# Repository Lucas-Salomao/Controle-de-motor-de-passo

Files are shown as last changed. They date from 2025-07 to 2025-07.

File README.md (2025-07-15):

# Controlador de Motor de Passo com Menu via Encoder e Display OLED

> Um sistema de controle preciso para motores de passo, com interface de usuário baseada em menu, desenvolvido para a plataforma ESP32 com PlatformIO.
> 

Este projeto oferece um controle detalhado para um motor de passo, utilizando um encoder rotativo para navegar por um menu de funções em um display OLED. O sistema é ideal para aplicações que exigem movimentos precisos e repetitivos, como em gabaritos, sistemas de automação de pequeno porte ou equipamentos de teste.

O usuário pode executar um ciclo completo de operação, posicionar o motor em um passo específico, ajustar a resolução do passo (micro-passo), configurar o tempo de acionamento de um relé e desabilitar o motor para movimento livre.

*Última atualização: 15 de Julho de 2025*

## ✨ Funcionalidades Principais

- **Interface de Menu Intuitiva:** Todas as funções são acessadas através de um menu no display OLED, controlado pelo encoder rotativo.
- **Ciclo de Operação Completo:** Executa uma volta completa, acionando um relé em cada passo por um tempo configurável.
- **Posicionamento Preciso:** Permite ao usuário escolher um passo exato (posição) para o qual o motor deve se mover.
- **Movimento Otimizado:** O motor sempre gira pelo caminho mais curto para alcançar a posição de destino.
- **Configuração de Micro-passo:** Suporte para ajustar a resolução do motor (Full, Half, 1/4, 1/8, e 1/16), permitindo um movimento mais suave e preciso.
- **Ajuste do Tempo do Relé:** O tempo em que o relé permanece ativo durante o ciclo completo pode ser ajustado e salvo pelo usuário.
- **Torque de Parada (Holding Torque):** As bobinas do motor permanecem energizadas na posição de destino para resistir a movimentos externos.
- **Modo de Giro Livre:** O motor pode ser facilmente desabilitado pelo menu para permitir o giro livre do eixo.
- **Altamente Configurável:** Pinos, passos do motor e outros parâmetros podem ser facilmente alterados no arquivo `config.h`.

## 🛠️ Componentes Necessários

| Componente | Quantidade | Observações |
| --- | --- | --- |
| ESP32 Dev Kit | 1 | Placa principal do projeto. |
| Driver de Motor de Passo A4988 | 1 | Ou similar (a lógica de micro-passo é para o A4988). |
| Motor de Passo NEMA 17 | 1 | Modelo de 200 passos/volta (1.8°). |
| Encoder Rotativo com Botão | 1 | Para entrada do usuário. |
| Display OLED I2C 0.96" | 1 | Modelo SSD1306 (128x64). |
| Módulo Relé 5V | 1 | Para acionar cargas externas. |
| Fonte de Alimentação Externa | 1 | Tensão e corrente compatíveis com o motor (ex: 12V 2A). |
| Cabos Jumper | Vários | Para realizar as conexões. |

## 📦 Software e Bibliotecas

Este projeto foi desenvolvido utilizando **PlatformIO** com o Visual Studio Code. As bibliotecas necessárias são gerenciadas automaticamente pelo `platformio.ini`.

- `adafruit/Adafruit GFX Library`: Biblioteca gráfica base para o display.
- `adafruit/Adafruit SSD1306`: Driver para o display OLED de 0.96".
- `Wire`: Para comunicação I2C com o display.

O projeto utiliza classes personalizadas (`StepperController`, `DisplayManager`, `EncoderHandler`) para modularizar o código, não dependendo de bibliotecas de motor externas como a AccelStepper.

## 🔌 Diagrama de Conexão (Wiring)

**Atenção:** A alimentação do motor (`VMOT` no A4988) **DEVE** vir de uma fonte externa. Não utilize o pino 5V/VIN do ESP32 para alimentar o motor. Conecte o GND da fonte externa ao GND do ESP32.

| Componente | Pino do Componente | Pino do ESP32 |
| --- | --- | --- |
| **Driver A4988** | `ENABLE` | `GPIO 27` |
|  | `STEP` | `GPIO 26` |
|  | `DIR` | `GPIO 25` |
|  | `MS1` | `GPIO 14` |
|  | `MS2` | `GPIO 12` |
|  | `MS3` | `GPIO 13` |
|  | `GND` | `GND` |
|  | `VDD` (Lógica) | `3.3V` ou `5V` |
|  | `VMOT` (Motor) | `+` da Fonte Externa |
|  | `GND` (Motor) | `-` da Fonte Externa |
| **Encoder** | `CLK` | `GPIO 18` |
|  | `DT` | `GPIO 19` |
|  | `SW` (Botão) | `GPIO 5` |
|  | `+` | `3.3V` |
|  | `GND` | `GND` |
| **Display OLED** | `SCL` | `GPIO 22` (Padrão I2C) |
|  | `SDA` | `GPIO` 21 (Padrão I2C) |
|  | `VCC` | `3.3V` |
|  | `GND` | `GND` |
| **Módulo Relé** | `IN` (Sinal) | `GPIO 32` |
|  | `VCC` | `5V` |
|  | `GND` | `GND` |

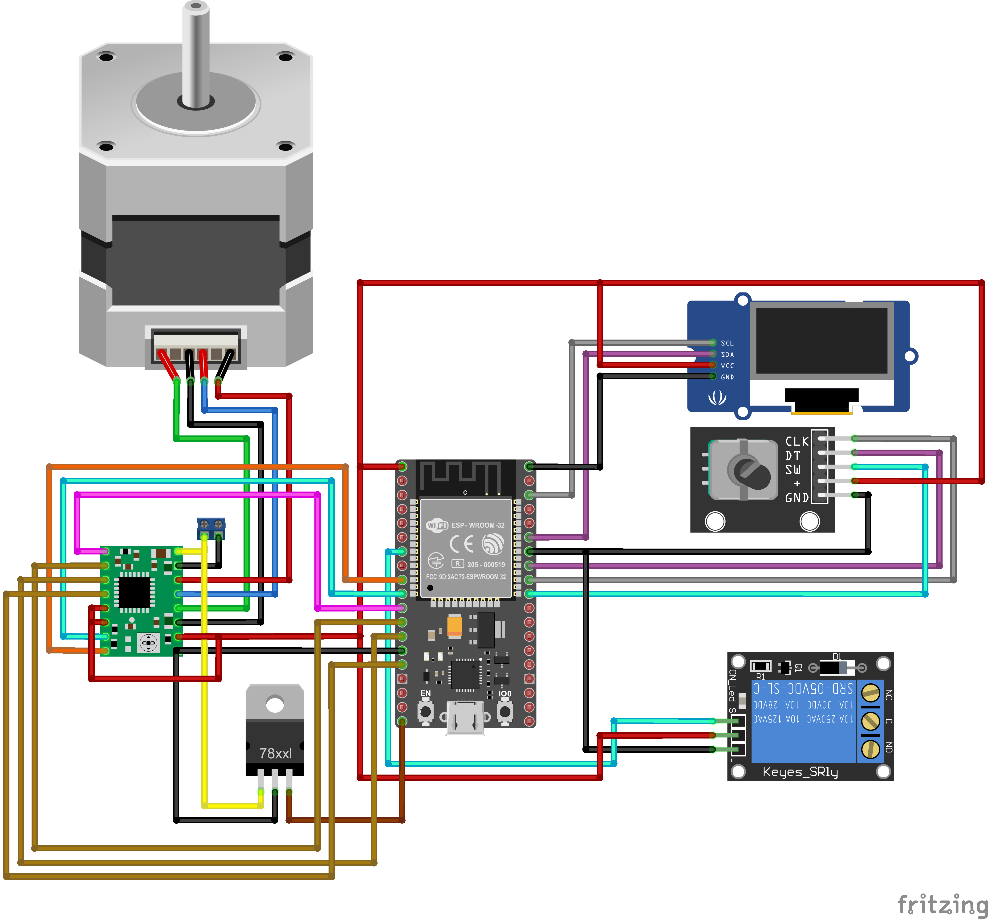
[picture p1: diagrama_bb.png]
Diagrama


## 📁 Estrutura do Projeto

O projeto está organizado em classes para facilitar a manutenção e a leitura do código.

```
.
├── platformio.ini         // Arquivo de configuração do PlatformIO
├── include
│   ├── config.h           // Configurações de pinos e parâmetros globais
│   ├── logo.h             // Bitmap da imagem de boot
│   ├── DisplayManager.h   // Cabeçalho da classe de controle do Display
│   ├── EncoderHandler.h   // Cabeçalho da classe de controle do Encoder
│   └── StepperController.h// Cabeçalho da classe de controle do Motor
└── src
    ├── main.cpp           // Lógica principal, máquina de estados e menus
    ├── DisplayManager.cpp   // Implementação da classe do Display
    ├── EncoderHandler.cpp   // Implementação da classe do Encoder
    └── StepperController.cpp// Implementação da classe do Motor

```

## ⚙️ Configuração

Antes de carregar o código, você pode verificar as configurações no arquivo `include/config.h` para que correspondam ao seu hardware.

### Mapeamento de Pinos

Se você precisar usar outros pinos no ESP32, pode alterá-los facilmente no `config.h`.

```
// --- Pinos de Controle de Micro-passo (A4988) ---
#define MS1_PIN         14
#define MS2_PIN         12
#define MS3_PIN         13

// Configurações do Motor de Passo
#define STEP_PIN        26
#define DIR_PIN         25
#define ENABLE_PIN      27

// Configurações do Encoder
#define ENCODER_CLK     18
#define ENCODER_DT      19
#define ENCODER_SW      5

// Configurações do Relé
#define RELAY_PIN       32

```

## 🚀 Como Usar

A operação do dispositivo é totalmente guiada pelo menu no display.

1. **Ligar o Dispositivo**
    - Ao receber energia, o display mostrará um logo por 2.5 segundos.
    - Em seguida, o Menu Principal será exibido.
2. **Navegando no Menu**
    - 🔄 **Girar o encoder:** Move o cursor de seleção (`>`) para cima ou para baixo na lista de opções. O menu rola automaticamente se houver mais itens do que o visível na tela.
    - 🖱️ **Pressionar o encoder (clique curto):** Seleciona a opção destacada.
3. **Opções do Menu**
    - **1. Ciclo Completo:**
        - Inicia um ciclo que dá uma volta completa no motor.
        - Em cada passo, o relé é ativado, o sistema aguarda um tempo (`RELAY_ON_TIME`), o relé é desativado e o motor avança para o próximo passo.
        - O progresso é exibido no display.
        - Pressione o encoder a qualquer momento para cancelar e retornar ao menu.
    - **2. Posicionamento:**
        - Leva a uma tela para definir um passo de destino.
        - Gire o encoder para selecionar o número do passo desejado. O total de passos disponíveis depende da configuração de micro-passo.
        - Pressione para confirmar. O motor se moverá para a posição e permanecerá travado.
    - **3. Micro-passo:**
        - Abre um menu para selecionar a resolução do motor (Full, 1/2, 1/4, 1/8 ou 1/16).
        - Uma resolução maior (ex: 1/16) resulta em mais passos por volta e um movimento mais suave.
        - Selecione uma opção e pressione para aplicar e voltar ao menu principal. A posição do motor será zerada.
    - **4. Tempo do Relé:**
        - Permite ajustar o tempo (em milissegundos) que o relé fica acionado durante o "Ciclo Completo".
        - Gire o encoder para aumentar ou diminuir o valor.
        - Pressione para salvar e voltar ao menu.
    - **5. Desligar Motor:**
        - Desativa as bobinas do motor, permitindo que o eixo seja girado manually (modo livre).
        - O display indicará "MOTOR DESLIGADO".
        - Para reativar, pressione o botão do encoder. O sistema voltará ao menu principal e habilitará o motor.

## 🔮 Melhorias Futuras

- [ ]  Salvar a última posição e as configurações de micro-passo e relé na memória NVS (EEPROM) do ESP32 para que não se percam ao desligar.
- [ ]  Adicionar um submenu de configurações para ajustar velocidade e aceleração do motor.
- [ ]  Implementar controle não-bloqueante do motor para que a interface continue responsiva durante o movimento.
- [ ]  Adicionar suporte a um sensor de fim de curso (`endstop`) para um ciclo de "homing" preciso.

## 📝 Licença

Este projeto é distribuído sob a Licença MIT.

Copyright (c) 2025 [Lucas Salomão]

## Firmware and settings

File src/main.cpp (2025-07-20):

#include <Arduino.h>
#include "StepperController.h"
#include "DisplayManager.h"
#include "EncoderHandler.h"
#include "config.h"
#include "logo.h"

// Protótipos das funções
void handleMainMenu();
void handleRunningCycle();
// void handleAngleSetup();
void handlePositioning();
void handleMotorDisabled();
void startFullCycle();
void finishCycle();
void startPositioning(int targetStep);
void handlePositioningSetup(); 
void handleMicrostepSetup();
void applyMicrostepSetting(int setting);
void handleRelayTimeSetup();
void handleRelayOffTimeSetup();

// Instâncias dos controladores
StepperController stepper;
DisplayManager display;
EncoderHandler encoder;

// Variáveis de estado
enum SystemState {
  MENU_MAIN,
  RUNNING_CYCLE,
  // ANGLE_SETUP,
  POSITIONING,
  POSITIONING_SETUP,
  MOTOR_DISABLED,
  MICROSTEP_SETUP,
  RELAY_TIME_SETUP,
  RELAY_OFF_TIME_SETUP
};

const char* menuItems[] = {
  "1. Ciclo Completo",
  "2. Posicionamento",
  "3. Micro-passo",
  "4. Tempo do Rele",
  "5. Tempo Rele Desl.",
  "6. Desligar Motor"
  // Adicione mais itens aqui se precisar no futuro
};
const int totalMenuItems = sizeof(menuItems) / sizeof(char*);

SystemState currentState = MENU_MAIN;
int targetAngle = 0;
int currentPosition = 0; // Posição atual em steps (0-199)
int targetStepValue = 0;
bool motorEnabled = true;

// --- NOVAS VARIÁVEIS PARA MICRO-PASSO ---
// 0=Full, 1=Half, 2=1/4, 3=1/8, 4=1/16
int currentMicrostep = 0; // Inicia em Full Step por padrão
// Array com os multiplicadores de passo
const int microstepMultipliers[] = {1, 2, 4, 8, 16};
// Variável para guardar os passos por volta atuais
int activeStepsPerRev = BASE_STEPS_PER_REV;

// Variáveis para controle de timing
unsigned long lastStepTime = 0;
unsigned long relayStartTime = 0;
int cycleStep = 0; // 0: relay on, 1: relay off wait, 2: move step, 3: step wait
int cyclePosition = 0; // posição atual no ciclo completo

bool resetMenuState = false;
unsigned long RELAY_ON_TIME = 1000;
unsigned long STEP_SETTLE_TIME = 1000;

void setup() {
  Serial.begin(115200);

  // --- INICIALIZAÇÃO DOS PINOS DE MICRO-PASSO ---
  pinMode(MS1_PIN, OUTPUT);
  pinMode(MS2_PIN, OUTPUT);
  pinMode(MS3_PIN, OUTPUT);
  
  // Inicializa os componentes
  stepper.begin();
  display.begin();
  encoder.begin();
  
  // Configuração do relé
  pinMode(RELAY_PIN, OUTPUT);
  digitalWrite(RELAY_PIN, HIGH);

  // Aplica a configuração de micro-passo inicial (Full Step)
  applyMicrostepSetting(currentMicrostep);
  
  Adafruit_SSD1306* logoDisplay = display.getDisplay();

  logoDisplay->clearDisplay();
  logoDisplay->drawBitmap(
      0, 0,
      epd_bitmap_logo,
      128, 64,
      SSD1306_WHITE
  );
  logoDisplay->display(); // Mostra o logo no display
  delay(2500);
  logoDisplay->clearDisplay(); // Limpa o display após mostrar o logo

  // Tela inicial
  // display.showMainMenu();

  // Tela inicial
  // MODIFICADO: Primeira chamada para a função de menu atualizada
  display.showMainMenu(menuItems, totalMenuItems, 0, 0);
  
  Serial.println("Sistema inicializado");
}

void loop() {
  // Atualiza encoder
  encoder.update();
  
  // Máquina de estados principal
  switch(currentState) {
    case MENU_MAIN:
      handleMainMenu();
      break;
      
    case RUNNING_CYCLE:
      handleRunningCycle();
      break;
      
    // case ANGLE_SETUP:
    //   handleAngleSetup();
    //   break;
      
    case POSITIONING:
      handlePositioning();
      break;

    case POSITIONING_SETUP:
       handlePositioningSetup();
       break;
      
    case MOTOR_DISABLED:
      handleMotorDisabled();
      break;

    case MICROSTEP_SETUP:
      handleMicrostepSetup();
      break;

    case RELAY_TIME_SETUP:
      handleRelayTimeSetup();
      break;
    
    case RELAY_OFF_TIME_SETUP: // <-- NOVO CASE
      handleRelayOffTimeSetup();
      break;
  }
  
  delay(10); // Pequeno delay para estabilidade
}

void handleMainMenu() {
  // MODIFICADO: Variáveis de estado do menu
  static int menuIndex = 0;         // Item atualmente selecionado
  static int menuStartIndex = 0;    // Item no topo da "janela" visível

  if (resetMenuState) {
    menuIndex = 0;
    menuStartIndex = 0;
    resetMenuState = false; // Desativa o sinalizador
    // Redesenha o menu com o estado reiniciado
    display.showMainMenu(menuItems, totalMenuItems, menuIndex, menuStartIndex);
  }

  int direction = encoder.getDirection();
  
  if (direction != 0) {
    // Navega pelo índice
    menuIndex += direction;
    
    // Lógica para o índice "dar a volta" na lista
    if (menuIndex < 0) menuIndex = totalMenuItems - 1;
    if (menuIndex >= totalMenuItems) menuIndex = 0;

    // --- LÓGICA DE ROLAGEM (SCROLL) DA JANELA ---
    // Se o item selecionado estiver acima da janela visível, rola para cima
    if (menuIndex < menuStartIndex) {
      menuStartIndex = menuIndex;
    }
    // Se o item selecionado estiver abaixo da janela visível, rola para baixo
    if (menuIndex >= menuStartIndex + MAX_VISIBLE_MENU_ITEMS) {
      menuStartIndex = menuIndex - MAX_VISIBLE_MENU_ITEMS + 1;
    }
    
    // O display agora só precisa saber qual item está no topo e qual está selecionado
    display.showMainMenu(menuItems, totalMenuItems, menuIndex, menuStartIndex);
  }
  
  // A lógica de seleção não muda, continua usando o menuIndex
  if (encoder.isPressed()) {
    switch (menuIndex) {
      case 0: // Ciclo completo
        startFullCycle();
        break;
      case 1: // Posicionamento
        currentState = POSITIONING_SETUP;
        targetStepValue = currentPosition;
        // targetAngle = 0;
        display.showPositioningSetup(targetStepValue);
        break;
      case 2: // Configurar Micro-passo
        currentState = MICROSTEP_SETUP;
        display.showMicrostepSetup(currentMicrostep);
        break;
      case 3: // Tempo do Relé <-- NOVA OPÇÃO
        currentState = RELAY_TIME_SETUP;
        // Chama a nova função de display (que criaremos a seguir)
        display.showRelayTimeSetup(RELAY_ON_TIME);
        break;
      case 4: // Tempo do Relé Desligado
        currentState = RELAY_OFF_TIME_SETUP;
        display.showRelayOffTimeSetup(STEP_SETTLE_TIME);
        break;
      case 5: // Desabilitar motor
        stepper.disable();
        motorEnabled = false;
        currentState = MOTOR_DISABLED;
        display.showMotorDisabled();
        break;
    }
    delay(200);
  }
}

// Aplica a configuração de micro-passo nos pinos MS e atualiza a variável de passos
void applyMicrostepSetting(int setting) {
  // Tabela de configuração do A4988
  // Setting | MS1   | MS2   | MS3   | Resolução
  // ------------------------------------------------
  // 0 (Full)| LOW   | LOW   | LOW   | 1
  // 1 (Half)| HIGH  | LOW   | LOW   | 1/2
  // 2 (1/4) | LOW   | HIGH  | LOW   | 1/4
  // 3 (1/8) | HIGH  | HIGH  | LOW   | 1/8
  // 4 (1/16)| HIGH  | HIGH  | HIGH  | 1/16
  
  bool ms1 = (setting == 1 || setting == 3 || setting == 4);
  bool ms2 = (setting == 2 || setting == 3 || setting == 4);
  bool ms3 = (setting == 4);

  digitalWrite(MS1_PIN, ms1 ? HIGH : LOW);
  digitalWrite(MS2_PIN, ms2 ? HIGH : LOW);
  digitalWrite(MS3_PIN, ms3 ? HIGH : LOW);

  // Atualiza a variável global de passos por revolução
  activeStepsPerRev = BASE_STEPS_PER_REV * microstepMultipliers[setting];
  currentMicrostep = setting; // Atualiza o estado atual

  // Zera a posição atual, pois a referência de passos mudou
  currentPosition = 0;
  
  Serial.printf("Micro-passo configurado para: %dx\n", microstepMultipliers[setting]);
  Serial.printf("Passos por volta agora: %d\n", activeStepsPerRev);
}

// Lida com a tela de configuração de micro-passo
void handleMicrostepSetup() {
  static int selectedMicrostep = currentMicrostep;

  int direction = encoder.getDirection();
  if (direction != 0) {
    selectedMicrostep += direction;
    if (selectedMicrostep < 0) selectedMicrostep = 4;
    if (selectedMicrostep > 4) selectedMicrostep = 0;
    display.showMicrostepSetup(selectedMicrostep);
  }

  if (encoder.isPressed()) {
    applyMicrostepSetting(selectedMicrostep);
    currentState = MENU_MAIN;
    // display.showMainMenu();
    resetMenuState = true;
    delay(200);
  }
}

void handleRelayTimeSetup() {
  static int selectedTime = RELAY_ON_TIME; // Inicia com o valor atual

  int direction = encoder.getDirection();
  if (direction != 0) {
    // Incrementa ou decrementa o tempo em 50ms
    selectedTime += direction * 50;
    
    // Define limites para o tempo (ex: 50ms a 5000ms)
    if (selectedTime < 50) selectedTime = 50;
    if (selectedTime > 5000) selectedTime = 5000;
    
    display.showRelayTimeSetup(selectedTime);
  }

  // Se o botão for pressionado, salva o valor e volta ao menu
  if (encoder.isPressed()) {
    RELAY_ON_TIME = selectedTime; // Salva o novo valor na variável global
    currentState = MENU_MAIN;
    resetMenuState = true;
    
    Serial.printf("Novo tempo do rele definido para: %d ms\n", RELAY_ON_TIME);
    delay(200);
  }
}

void handleRelayOffTimeSetup() {
  static int selectedTime = STEP_SETTLE_TIME;

  int direction = encoder.getDirection();
  if (direction != 0) {
    selectedTime += direction * 50;
    if (selectedTime < 50) selectedTime = 50;
    if (selectedTime > 5000) selectedTime = 5000;
    display.showRelayOffTimeSetup(selectedTime);
  }

  if (encoder.isPressed()) {
    STEP_SETTLE_TIME = selectedTime;
    currentState = MENU_MAIN;
    resetMenuState = true;
    Serial.printf("Novo tempo do rele DESLIGADO definido para: %d ms\n", STEP_SETTLE_TIME);
    delay(200);
  }
}

void handlePositioningSetup() {
    int direction = encoder.getDirection();
    // Ajusta o passo alvo. O encoder gira a lista de passos possíveis.
    if(direction != 0) {
      targetStepValue += direction;
      
      // Lógica para "dar a volta" (wrap-around)
      if (targetStepValue < 0) targetStepValue = activeStepsPerRev - 1;
      if (targetStepValue >= activeStepsPerRev) targetStepValue = 0;
      
      display.showPositioningSetup(targetStepValue);
    }

    if(encoder.isPressed()) {
      // Confirma o passo alvo e inicia o posicionamento
      currentState = POSITIONING;
      startPositioning(targetStepValue);
      delay(200);
    }
}

void startFullCycle() {
  currentState = RUNNING_CYCLE;
  cycleStep = 0;
  cyclePosition = 0;
  currentPosition = 0;
  stepper.enable();
  motorEnabled = true;
  
  // Inicia o primeiro passo do ciclo
  digitalWrite(RELAY_PIN, LOW);
  relayStartTime = millis();
  
  display.showCycleProgress(cyclePosition, activeStepsPerRev);
  Serial.println("Iniciando ciclo completo");
}

void handleRunningCycle() {
  unsigned long currentTime = millis();
  
  switch(cycleStep) {
    case 0: // O relé está LIGADO, esperando o tempo definido.
      // A constante RELAY_ON_TIME vem de config.h (500ms)
      if (currentTime - relayStartTime >= RELAY_ON_TIME) {
        // O tempo de 500ms passou. Agora, desligamos o relé e damos o passo.
        digitalWrite(RELAY_PIN, HIGH); // Desliga o relé
        stepper.moveOneStep();         // Move um passo imediatamente

        // Atualiza as variáveis de posição e o display
        currentPosition = (currentPosition + 1) % activeStepsPerRev;
        cyclePosition++;
        display.showCycleProgress(cyclePosition, activeStepsPerRev);
        
        // Guarda o tempo do passo para a pequena pausa de estabilização
        lastStepTime = currentTime;
        cycleStep = 1; // Vai para o estado de pausa
      }
      break;
      
    case 1: // Pausa de estabilização após o passo, antes de começar o próximo ciclo.
      if (currentTime - lastStepTime >= STEP_SETTLE_TIME) {
        // A pausa terminou. Vamos verificar se o ciclo completo acabou.
        if (cyclePosition >= activeStepsPerRev) {
          // Sim, todos os passos foram dados.
          finishCycle();
        } else {
          // Não, ainda há passos a dar. Prepara para o próximo ciclo.
          digitalWrite(RELAY_PIN, LOW); // Liga o relé novamente
          relayStartTime = currentTime; // Reinicia o timer do relé
          cycleStep = 0;                // Volta para o estado 0 para esperar os 500ms
        }
      }
      break;
  }
  
  // A lógica para cancelar com o botão permanece a mesma e funciona perfeitamente.
  if (encoder.isPressed()) {
    digitalWrite(RELAY_PIN, HIGH); // Garante que o relé seja desligado ao cancelar
    currentState = MENU_MAIN;
    resetMenuState = true;
    Serial.println("Ciclo cancelado");
    delay(200);
  }
}

void finishCycle() {
  currentState = MENU_MAIN;
  display.showCycleComplete();
  delay(2000);
  resetMenuState = true;
  Serial.println("Ciclo completo finalizado");
}

// void handleAngleSetup() {
//   int direction = encoder.getDirection();
//   // Ajuste do ângulo com encoder
//   if(direction != 0) {
//     targetAngle += direction * 18; // Incremento de 1.8 graus (18 décimos)
    
//     // Limita entre 0 e 360 graus
//     if(targetAngle < 0) targetAngle = 3582; // 358.2 graus
//     if(targetAngle >= 3600) targetAngle = 0;
    
//     display.showAngleSetup(targetAngle);
//   }
  
//   if(encoder.isPressed()) {
//     // Confirma ângulo e inicia posicionamento
//     currentState = POSITIONING;
//     startPositioning();
//     delay(200);
//   }
// }

void startPositioning(int targetStep) {
  stepper.enable();
  motorEnabled = true;

  // float anglePerStep = 360.0 / activeStepsPerRev;
  
  // // Calcula posição alvo em steps
  // int targetStep = round((targetAngle / 10.0) / anglePerStep);
  // Calcula menor caminho
  int stepsToMove = targetStep - currentPosition;

  int halfWay = activeStepsPerRev / 2;
  
  if(stepsToMove > halfWay) {
    stepsToMove -= activeStepsPerRev;
  } else if(stepsToMove < -halfWay) {
    stepsToMove += activeStepsPerRev;
  }
  
  display.showPositioning(targetStep, stepsToMove);
  
  // Executa movimento
  if(stepsToMove != 0) {
    stepper.moveSteps(stepsToMove);
    // currentPosition = targetStep;
  }
  currentPosition = targetStep;
  
  // Mantém motor energizado para travar posição
  // Serial.printf("Posicionado em %.1f graus (%d steps)\n", targetAngle/10.0, currentPosition);
  Serial.printf("Posicionado no passo %d\n", currentPosition);

  // Retorna ao menu após 2 segundos
  delay(2000);
  currentState = MENU_MAIN;
  resetMenuState = true;
}

void handlePositioning() {
  // Estado transitório - o posicionamento é feito imediatamente
  // Este método existe para futuras expansões
}

void handleMotorDisabled() {
  if(encoder.isPressed()) {
    // Reabilita motor e volta ao menu
    stepper.enable();
    motorEnabled = true;
    currentState = MENU_MAIN;
    resetMenuState = true;
    Serial.println("Motor reabilitado");
    delay(200);
  }
}


// ====== TESTE 1: MOTOR DE PASSO ======
// #include <Arduino.h>

// void setup() {
//     Serial.begin(115200);
    
//     pinMode(26, OUTPUT); // STEP
//     pinMode(25, OUTPUT); // DIR  
//     pinMode(27, OUTPUT); // ENABLE
    
//     digitalWrite(27, LOW); // Habilita motor
//     digitalWrite(25, LOW); // Direção horária
    
//     Serial.println("Teste do motor de passo iniciado");
// }

// void loop() {
//     // Move 10 passos
//     for(int i = 0; i < 10000; i++) {
//         digitalWrite(26, HIGH);
//         delayMicroseconds(500);
//         digitalWrite(26, LOW);
//         delayMicroseconds(500);
//         Serial.printf("Passo %d\n", i+1);
//     }
    
//     delay(2000);
    
//     // Inverte direção
//     digitalWrite(25, !digitalRead(25));
//     Serial.println("Invertendo direção");
// }

// ====== TESTE 3: ENCODER ROTATIVO ======
// #include <Arduino.h>
// #include <Wire.h>
// #include <Adafruit_GFX.h>
// #include <Adafruit_SSD1306.h>
// void setup() {
//     Serial.begin(115200);
    
//     pinMode(18, INPUT_PULLUP); // CLK
//     pinMode(19, INPUT_PULLUP); // DT
//     pinMode(5, INPUT_PULLUP);  // SW
    
//     Serial.println("Teste do encoder iniciado");
//     Serial.println("Gire o encoder e pressione o botão");
// }

// void loop() {
//     static int lastClk = HIGH;
//     static int lastButton = HIGH;
    
//     int clk = digitalRead(18);
//     int dt = digitalRead(19);
//     int button = digitalRead(5);
    
//     // Detecta rotação
//     if(clk != lastClk) {
//         if(dt != clk) {
//             Serial.println("Encoder: HORÁRIO");
//         } else {
//             Serial.println("Encoder: ANTI-HORÁRIO");
//         }
//         lastClk = clk;
//     }
    
//     // Detecta botão
//     if(button == LOW && lastButton == HIGH) {
//         Serial.println("Botão PRESSIONADO");
//         delay(200); // Debounce
//     }
//     lastButton = button;
    
//     delay(10);
// }

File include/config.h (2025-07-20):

#ifndef CONFIG_H
#define CONFIG_H

// --- Pinos de Controle de Micro-passo (A4988) ---
#define MS1_PIN         14
#define MS2_PIN         12
#define MS3_PIN         13

// Configurações do Motor de Passo
#define STEP_PIN        26
#define DIR_PIN         25
#define ENABLE_PIN      27
#define BASE_STEPS_PER_REV   200
#define STEP_DELAY_US   1000  // Microsegundos entre pulsos

// Configurações do Display OLED
#define SCREEN_WIDTH    128
#define SCREEN_HEIGHT   64
#define OLED_RESET      -1
#define SCREEN_ADDRESS  0x3C

// Defina aqui quantos itens do menu principal devem ser visíveis na tela.
// Para sua tela de 64px de altura, 3 ou 4 é um bom valor.
#define MAX_VISIBLE_MENU_ITEMS 3

// Configurações do Encoder
#define ENCODER_CLK     18
#define ENCODER_DT      19
#define ENCODER_SW      5
#define ENCODER_PULSES_PER_STEP 4

// Configurações do Relé
#define RELAY_PIN       32

// Configurações do sistema
#define ANGLE_INCREMENT 18    // 1.8 graus em décimos (18 = 1.8°)

#endif

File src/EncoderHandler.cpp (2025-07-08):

#include "EncoderHandler.h"

EncoderHandler::EncoderHandler() {
    direction = 0;
    buttonPressed = false;
    lastButtonState = HIGH;
    lastDebounceTime = 0;
}

void EncoderHandler::begin() {
    pinMode(ENCODER_CLK, INPUT_PULLUP);
    pinMode(ENCODER_DT, INPUT_PULLUP);
    pinMode(ENCODER_SW, INPUT_PULLUP);
    
    lastClkState = digitalRead(ENCODER_CLK);
    
    Serial.println("EncoderHandler inicializado");
}

void EncoderHandler::update() {
    // --- Lógica de Rotação (Inalterada) ---
    int currentClkState = digitalRead(ENCODER_CLK);
    
    if (currentClkState != lastClkState) {
        // Incrementa ou decrementa o contador de pulsos a cada pulso detectado
        if (digitalRead(ENCODER_DT) != currentClkState) {
            pulseCounter++; // Sentido horário
        } else {
            pulseCounter--; // Sentido anti-horário
        }

        // Verifica se o contador atingiu o limiar definido em config.h
        if (abs(pulseCounter) >= ENCODER_PULSES_PER_STEP) {
            // Se atingiu, define a direção do passo e zera o contador
            if (pulseCounter > 0) {
                direction = 1;
                Serial.println("Encoder: PASSO HORÁRIO");
            } else {
                direction = -1;
                Serial.println("Encoder: PASSO ANTI-HORÁRIO");
            }
            pulseCounter = 0; // Zera o contador para o próximo passo
        }
        
        lastClkState = currentClkState;
    }
    
    // --- Lógica de Detecção do Botão (Corrigida) ---
    static int debouncedButtonState = HIGH; // Variável estática para manter o estado estável
    int buttonReading = digitalRead(ENCODER_SW);

    // Se a leitura atual for diferente da anterior (ruído ou ação real), reinicie o timer.
    if (buttonReading != lastButtonState) {
        lastDebounceTime = millis();
    }

    // Se o tempo desde a última mudança for maior que o debounce...
    if ((millis() - lastDebounceTime) > debounceDelay) {
        // ...o sinal está estável. Verificamos se houve uma mudança de estado.
        if (buttonReading != debouncedButtonState) {
            debouncedButtonState = buttonReading;

            // Se o novo estado estável for "pressionado" (LOW), acionamos o evento.
            if (debouncedButtonState == LOW) {
                Serial.println("Botão PRESSIONADO");
                buttonPressed = true;
            }
        }
    }
    
    // Atualiza o último estado lido para a próxima iteração.
    lastButtonState = buttonReading;
}

int EncoderHandler::getDirection() {
    int currentDirection = direction;
    direction = 0; // Reset após leitura
    return currentDirection;
}

bool EncoderHandler::isPressed() {
    if (buttonPressed) {
        buttonPressed = false; // Reset após leitura
        return true;
    }
    return false;
}

void EncoderHandler::resetDirection() {
    direction = 0;
}

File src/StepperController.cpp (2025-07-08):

#include "StepperController.h"

StepperController::StepperController() {
    enabled = false;
    currentDirection = 1;
}

void StepperController::begin() {
    pinMode(STEP_PIN, OUTPUT);
    pinMode(DIR_PIN, OUTPUT);
    pinMode(ENABLE_PIN, OUTPUT);
    
    digitalWrite(STEP_PIN, LOW);
    digitalWrite(DIR_PIN, LOW);
    digitalWrite(ENABLE_PIN, HIGH); // HIGH = desabilitado na maioria dos drivers
    
    enabled = false;
    
    Serial.println("StepperController inicializado");
}

void StepperController::enable() {
    digitalWrite(ENABLE_PIN, LOW); // LOW = habilitado
    enabled = true;
    Serial.println("Motor de passo habilitado");
}

void StepperController::disable() {
    digitalWrite(ENABLE_PIN, HIGH); // HIGH = desabilitado
    enabled = false;
    Serial.println("Motor de passo desabilitado");
}

void StepperController::setDirection(bool clockwise) {
    currentDirection = clockwise ? 1 : -1;
    digitalWrite(DIR_PIN, clockwise ? LOW : HIGH);
    delayMicroseconds(10); // Pequeno delay para estabilizar sinal de direção
}

void StepperController::moveOneStep(bool clockwise) {
    if (!enabled) return;
    
    setDirection(clockwise);
    
    // Gera pulso de step
    digitalWrite(STEP_PIN, HIGH);
    delayMicroseconds(STEP_DELAY_US / 2);
    digitalWrite(STEP_PIN, LOW);
    delayMicroseconds(STEP_DELAY_US / 2);
    
    Serial.printf("Step executado - direção: %s\n", clockwise ? "horário" : "anti-horário");
}

void StepperController::moveSteps(int steps) {
    if (!enabled || steps == 0) return;
    
    bool clockwise = steps > 0;
    int absSteps = abs(steps);
    
    setDirection(clockwise);
    
    Serial.printf("Movendo %d steps - direção: %s\n", absSteps, clockwise ? "horário" : "anti-horário");
    
    for (int i = 0; i < absSteps; i++) {
        // Gera pulso de step
        digitalWrite(STEP_PIN, HIGH);
        delayMicroseconds(STEP_DELAY_US / 2);
        digitalWrite(STEP_PIN, LOW);
        delayMicroseconds(STEP_DELAY_US / 2);
        
        // Pequeno delay entre steps para suavidade
        delay(5);
    }
    
    Serial.printf("Movimento de %d steps concluído\n", absSteps);
}

bool StepperController::isEnabled() {
    return enabled;
}

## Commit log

2025-06-16 inclusão de diagrama
    [diagrama.fzz]
2025-07-08 ajuste na lógica do rele e inclusao de menu de ajuste do tempo do relé
2025-07-11 alteração de lógica de posicionamento de ângulo para passo
2025-07-20 adicionado o controle de tempo de relé desligado
